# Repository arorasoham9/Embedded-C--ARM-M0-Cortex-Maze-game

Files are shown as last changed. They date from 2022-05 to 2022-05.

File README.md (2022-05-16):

# MazeGame

Links to Parts:
Adafruit LIS3DH Triple-Axis Accelerometer (+-2g/4g/8g/16g) : ID 2809 : $4.95 : Adafruit Industries, Unique & fun DIY electronics and kits
Mini Metal Speaker w/ Wires - 8 ohm 0.5W : ID 1890 : $1.95 : Adafruit Industries, Unique & fun DIY electronics and kits

What kinds of internal peripherals will you use? (at least four)
SPI (Screen), I2C (Accelerometer), Timer (Game time), DAC (Game music), GPIO (Buttons)

What kinds of external interface formats will you use? (at least two)
SPI, I2C, GPIO, Analog

Briefly, what are you making and what are you making it out of?
We are going to make a handheld maze game where you control the ball’s movement by rotating the device relative to gravity. The game will be displayed on the MSP2202 TFT LCD Display and angular position will be provided by an LIS3DH triple-axis accelerometer. Tetris music will be played with the MIDI interpreter used in lab via a M2850-8B-0L03R speaker powered by an LM386 audio amplifier. The LM386 is designed for low voltage consumer applications and is adequately powered by a 5 volt supply. The 24AA32AF EEPROM will save the high score even after the device is shut down and restarted. Five tactile push buttons (up/down/left/right/select) will allow the user to navigate any necessary prompts and menus.

Mazes will be dynamically generated. As mazes are completed, they will increase in size and number of rotations required to solve them. A reasonable minimum/maximum rotation limit will be put in place for each size of maze generated.

Briefly, how will you demonstrate it?
We will have the TA play the game. Each maze must be completed within a time limit or the speaker will buzz. The score achieved and the all-time high score will be displayed. The player will be given the choice to start a new game.

Briefly, how will we define the criteria for a successful project? (If your demonstration does not meet these criteria, your score will be negatively affected.)
The rotation based control should track the device’s position accurately and be free of noise/glitches. The game should be able to be played and completed by any adult with no instructions given (any instructions should be easily accessible within the device itself). The maze levels should gradually increase in size as each subsequent maze is completed. The maze size will level off at a point before the maze paths become hard to discern (however we expect people to lose or quit before this point is reached). The player’s score should be a summation of the time left on the countdown for each maze successfully completed. For example, if a certain level has a time limit of 45 seconds, and the player completes the maze in 30 seconds, 15 points will be added to the player’s total score. The high score should be saved and able to be recalled even after the device is shutdown and powered back on. Music should be clearly audible and free of noise.

#CONCLUSION

What did you build? 	
What components (including model numbers) did you use? 	
What challenges did you face, and how did you overcome them? 	
What do you recommend to anyone doing the same thing or using the same components in the future?

We built a maze game that was controlled by rotation of the board. The maze was dynamically generated and increased in size when each level was passed. Players had a set amount of time, which increased as the game continued, to solve each level. Time remaining and current score were displayed on the maze screen. Level score was equal to the amount of time remaining to complete the maze. Menus at start, next level, and end of game were navigated using push buttons and GPIO. After the level or game ended, score was displayed and the player could choose to continue/quit or start a new game. Navigation within the maze was controlled by an accelerometer that interfaced with I2C. EEPROM was used with I2C to save the high score when the game was reset or power was turned off and on. Tetris music played during gameplay and was set up with a MIDI interpreter and DAC output.
The game was displayed on the MSP2202 TFT LCD Display and angular position was provided by an LIS3DH triple-axis accelerometer. 24AA32AF EEPROM allowed our team to save the high score after power cycles. An LM386 amplifier drove a small 0.5 watt M2850-8B-0L03R speaker. Generic 6mm buttons provided the user-input, and LM1117 regulators allowed the team to power the components at their respective voltages.
One major issue that we encountered was related to the randomness of the maze that we were generating. When we initially wrote the maze program we used time.h to seed the random number generator. However, we learned that time.h cannot be used in our microcontroller. After this, we followed the directions on the references site about seeding random with a timer. Our first attempt at this failed and the mazes were still not random. We realized that this was due to the fact that we were calling srand(TIM2->CNT) at the same time each time the game started. In order to fix this we waited for a button to be pressed before we seeded srand, to ensure a different seed each time. 

We also struggled to correctly display colors. We used GIMP to generate the ball, and its output was not displaying colors correctly. We got around this by copying the number of the color we wanted into the array manually. However, the color was lime green against a white background, and the lack of contrast made the ball difficult to view if the player held the maze screen far away.

One final issue we encountered involved music. We used a weak 0.5 W speaker connected to a LM386 amplifier, and getting output at a reasonable volume was difficult. We needed overly complex circuitry to get volume where you didn’t need to place your ear near the speaker to hear. We also struggled with enabling and disabling the music at correct times in the code. When music was stopped and restarted, there was a remaining contribution that interfered with the sound. To fix this, we disabled the timer and set the voices array values to zero before restarting the music. We also did not correctly set the interrupt priority for the music, and the sound clicked as a result. We did not realize this because of the low output of the speaker, but it became clear during the demonstration when we hooked up the output to the lab speakers. If we had tested with the lab speaker, we would likely have been able to fix this issue.

I would recommend a similar project to teams in the future. We ran into many challenges arriving at our final design, however all problems were manageable with proper time management and teamwork. Every component worked well with the exception of the LM386 audio amplifier. We found the LM386 to be very temperamental and prone to noise on our breadboard, and the suggested schematics in the datasheet had to be modified to attain usable results in our case. A small issue we had with the LIS3DH accelerometer was that the datasheet I2C section indicated that a repeated start bit must be sent when the master is receiving data from the accelerometer. We couldn’t figure out how to do this, but after research we found that the repeated start wasn’t necessary- sending a stop bit first followed by a start bit also functioned properly. Once this was figured out the accelerometer worked flawlessly.

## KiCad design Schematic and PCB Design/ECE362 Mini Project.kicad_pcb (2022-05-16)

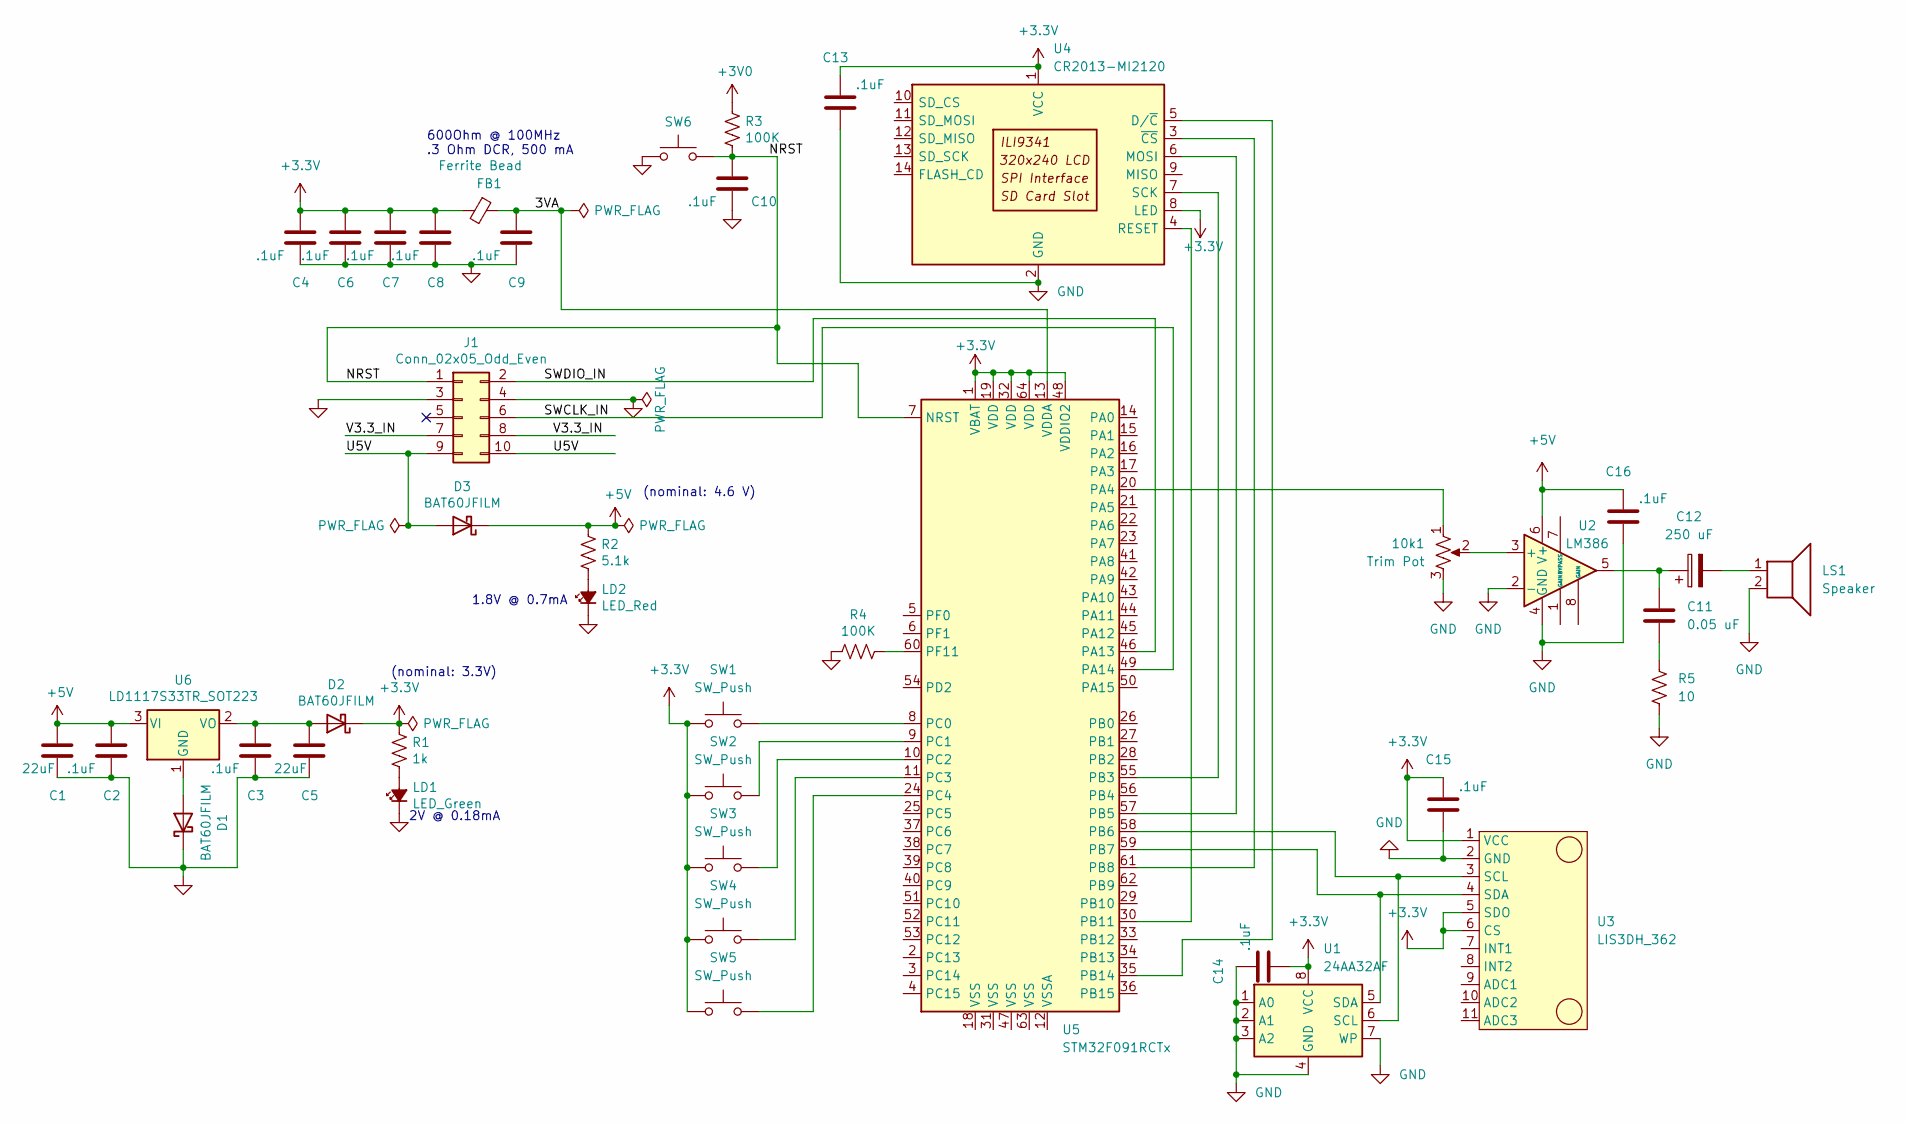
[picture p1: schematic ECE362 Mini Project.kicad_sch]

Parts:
10k1: Trim Pot; Potentiometer_Vishay_148-149_Single_Vertical
C1, C5: 22uF; C_0805_2012Metric_Pad1.18x1.45mm_HandSolder
C2, C3, C4, C6, C7, C8, C9, C10, C13, C14, C15, C16: .1uF; C_0805_2012Metric_Pad1.18x1.45mm_HandSolder
C11: 0.05 uF; C_0805_2012Metric_Pad1.18x1.45mm_HandSolder
C12: 250 uF; CP_Radial_D8.0mm_P3.50mm
D1, D2, D3: BAT60JFILM; D_SOD-323
FB1: Ferrite Bead; L_0805_2012Metric_Pad1.15x1.40mm_HandSolder
J1: Conn_02x05_Odd_Even; IDC-Header_2x05_P2.54mm_Vertical
LD1: LED_Green; LED_0805_2012Metric
LD2: LED_Red; LED_0805_2012Metric
LS1: Speaker; SolderWire-0.5sqmm_1x02_P4.6mm_D0.9mm_OD2.1mm
R1: 1k; R_0805_2012Metric_Pad1.20x1.40mm_HandSolder
R2: 5.1k; R_0805_2012Metric_Pad1.20x1.40mm_HandSolder
R3, R4: 100K; R_0805_2012Metric_Pad1.20x1.40mm_HandSolder
R5: 10; R_0805_2012Metric_Pad1.20x1.40mm_HandSolder
SW1, SW2, SW3, SW4, SW5, SW6: SW_Push; SW_PUSH_6mm
U1: 24AA32AF; DIP-8_W7.62mm
U2: LM386; DIP-8_W7.62mm
U3: LIS3DH_362
U4: CR2013-MI2120
U5: STM32F091RCTx; LQFP-64_10x10mm_P0.5mm
U6: LD1117S33TR_SOT223; SOT-223-3_TabPin2

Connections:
+3V0: R3.1
+3V3: C4.1, C6.1, C7.1, C8.1, C13.2, C14.1, C15.2, D2.1 (K), FB1.2, R1.1, SW1.1, SW2.1, SW3.1, SW4.1, SW5.1, U1.8 (VCC), U3.1 (VCC), U3.5 (SDO), U3.6 (CS), U4.1 (VCC), U4.8 (LED), U5.1 (VBAT), U5.19 (VDD), U5.32 (VDD), U5.48 (VDDIO2), U5.64 (VDD)
+5V: C1.1, C2.1, C16.2, D3.1 (K), R2.1, U2.6 (V+), U6.3 (VI)
/3VA: C9.1, FB1.1, U5.13 (VDDA)
/NRST: C10.1, J1.1, R3.2, SW6.2, U5.7 (NRST)
/SWCLK_IN: J1.6, U5.49 (PA14)
/SWDIO_IN: J1.2, U5.46 (PA13)
/U5V: D3.2 (A), J1.9, J1.10
/V3.3_IN: J1.7, J1.8
GND: 10k1.3, C1.2, C2.2, C3.2, C4.2, C5.2, C6.2, C7.2, C8.2, C9.2, C10.2, C13.1, C14.2, C15.1, C16.1, D1.1 (K), J1.3, J1.4, LD1.1 (K), LD2.1 (K), LS1.2, R4.2, R5.2, SW6.1, U1.1 (A0), U1.2 (A1), U1.3 (A2), U1.4 (GND), U1.7 (WP), U2.2 (-), U2.4 (GND), U3.2 (GND), U4.2 (GND)
unnamed: 10k1.2, U2.3 (+)
unnamed: C3.1, C5.1, D2.2 (A), U6.2 (VO)
unnamed: C11.1, C12.1, U2.5
unnamed: C11.2, R5.1
unnamed: D1.2 (A), U6.1 (GND)
unnamed: LD1.2 (A), R1.2
unnamed: LD2.2 (A), R2.2
unnamed: C12.2, LS1.1
unnamed: U1.5 (SDA), U3.4 (SDA), U5.59 (PB7)
unnamed: U4.6 (MOSI), U5.57 (PB5)
unnamed: SW1.2, U5.8 (PC0)
unnamed: SW2.2, U5.9 (PC1)
unnamed: SW3.2, U5.10 (PC2)
unnamed: SW4.2, U5.11 (PC3)
unnamed: 10k1.1, U5.20 (PA4)
unnamed: SW5.2, U5.24 (PC4)
unnamed: U4.4 (RESET), U5.30 (PB11)
unnamed: U4.5 (D/~C), U5.35 (PB14)
unnamed: U4.7 (SCK), U5.55 (PB3)
unnamed: U1.6 (SCL), U3.3 (SCL), U5.58 (PB6)
unnamed: R4.1, U5.60 (PF11)
unnamed: U4.3 (~CS), U5.61 (PB8)

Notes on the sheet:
(nominal: 3.3V)
2V @ 0.18mA
600Ohm @ 100MHz .3 Ohm DCR, 500 mA
1.8V @ 0.7mA
(nominal: 4.6 V)

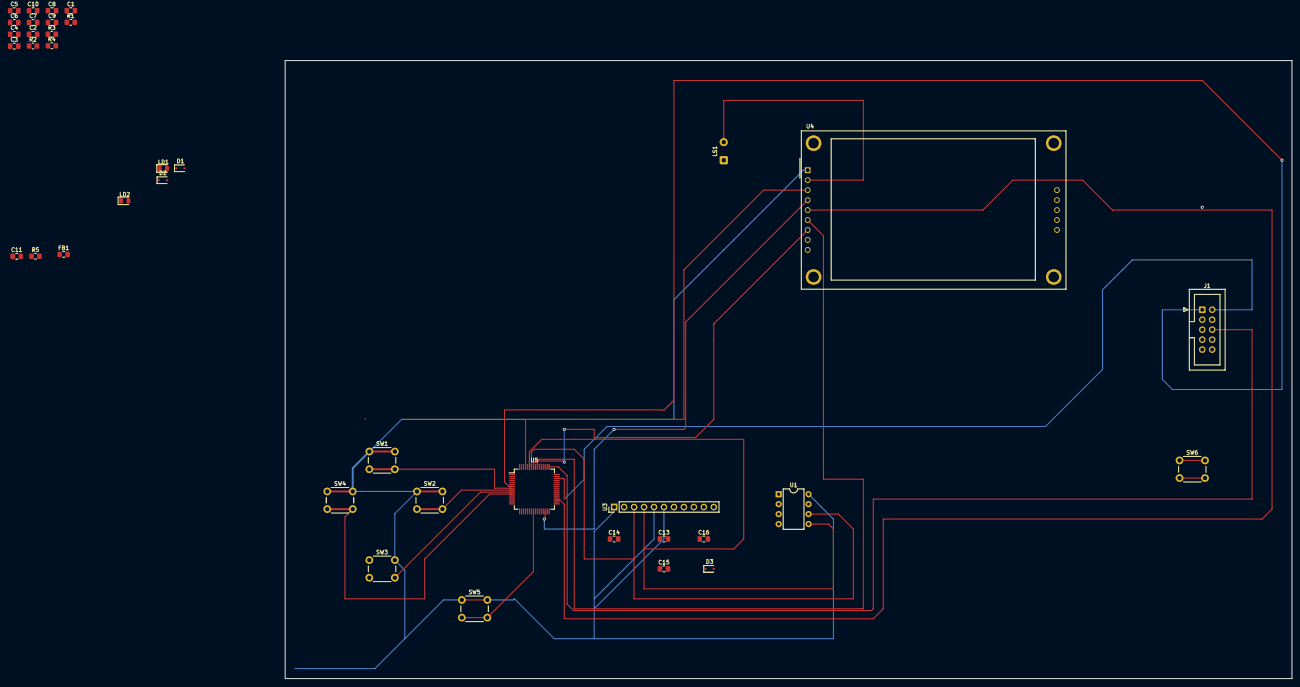
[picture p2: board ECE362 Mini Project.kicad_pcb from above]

Board: 2 copper layers, 256.5 x 157.5 mm, 39 parts (1 on the bottom side), 27 nets.

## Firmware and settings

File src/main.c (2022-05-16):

#include "stm32f0xx.h"
#include <string.h>
#include "lcd.h"
#include "speaker.h"
#include "midi.h"
char** generate_maze(int, int);
void destroyArray(char** arr);
//extern const Picture background; // A 240x320 background image
MIDI_Player * music;
int time_remaining;
int current_score = 0;
int high_score = 0;
int num_rows = 13;
int num_cols = 13;
int game_number = 0;
int level_score = 60;

int up = 0;
int down = 0;
int left = 0;
int right = 0;
int ball_row = 1;
int ball_col = 1;

char ** global_maze;

//===========================================================================
// GIMP images
//===========================================================================
/* GIMP RGB C-Source image dump (line.c) */
static const struct {
  unsigned int      width;
  unsigned int      height;
  unsigned int      bytes_per_pixel; /* 2:RGB16, 3:RGB, 4:RGBA */
  unsigned char     pixel_data[8 * 8 * 3 + 1];
} line = {
  8, 8, 3,
  "\000\000\000\000\000\000\000\000\000\000\000\000\000\000\000\000\000\000\000\000\000\000\000\000\000\000\000\000\000\000\000\000\000\000\000\000"
  "\000\000\000\000\000\000\000\000\000\000\000\000\000\000\000\000\000\000\000\000\000\000\000\000\000\000\000\000\000\000\000\000\000\000\000\000"
  "\000\000\000\000\000\000\000\000\000\000\000\000\000\000\000\000\000\000\000\000\000\000\000\000\000\000\000\000\000\000\000\000\000\000\000\000"
  "\000\000\000\000\000\000\000\000\000\000\000\000\000\000\000\000\000\000\000\000\000\000\000\000\000\000\000\000\000\000\000\000\000\000\000\000"
  "\000\000\000\000\000\000\000\000\000\000\000\000\000\000\000\000\000\000\000\000\000\000\000\000\000\000\000\000\000\000\000\000\000\000\000\000"
  "\000\000\000\000\000\000\000\000\000\000\000\000",
};
/* GIMP RGB C-Source image dump (green_square.c) */

static const struct {
  unsigned int   width;
  unsigned int   height;
  unsigned int   bytes_per_pixel; // 2:RGB16, 3:RGB, 4:RGBA
  unsigned char  pixel_data[8 * 8 * 2 + 1];
} ball = {
  8, 8, 2,
  "\262_\262_\262_\262_\262_\262_\262_\262_\262_\262_\262_\262_\262_\262_\262_\262_\262_\262_\262_\262_\262_\262_\262_\262_\262_\262_\262_"
  "\262_\262_\262_\262_\262_\262_\262_\262_\262_\262_\262_\262_\262_\262_\262_\262_\262_\262_\262_\262_\262_\262_\262_\262_\262_\262_\262_"
  "\262_\262_\262_\262_\262_\262_\262_\262_\262_\262_\262_\262_\262_\262_\262_\262_\262_\262_\262_\262_\262_\262_\262_\262_\262_\262_\262_"
  "\262_\262_\262_\262_\262_\262_\262_\262_\262_\262_\262_\262_\262_\262_\262_\262_\262_\262_\262_\262_\262_\262_\262_\262_\262_\262_\262_"
  "\262_\262_\262_\262_\262_\262_\262_\262_\262_\262_\262_\262_\262_\262_\262_\262_\262_\262_\262_\262_\262_\262_\262_\262_\262_\262_\262_"
  "\262_\262_\262_\262_\262_\262_\262_\262_\262_\262_\262_\262_\262_\262_\262_\262_\262_\262_\262_\262_\262_\262_\262_\262_\262_\262_\262_"
  "\262_\262_\262_\262_\262_\262_\262_\262_\262_\262_\262_\262_\262_\262_\262_\262_\262_\262_\262_\262_\262_\262_\262_\262_\262_\262_\262_"
  "\262_\262_\262_",
};
/* GIMP RGB C-Source image dump (white_square.c) */
static const struct {
  unsigned int   width;
  unsigned int   height;
  unsigned int   bytes_per_pixel; /* 2:RGB16, 3:RGB, 4:RGBA */
  unsigned char  pixel_data[8 * 8 * 3 + 1];
} white_square = {
  8, 8, 3,
  "\377\377\377\377\377\377\377\377\377\377\377\377\377\377\377\377\377\377"
  "\377\377\377\377\377\377\377\377\377\377\377\377\377\377\377\377\377\377"
  "\377\377\377\377\377\377\377\377\377\377\377\377\377\377\377\377\377\377"
  "\377\377\377\377\377\377\377\377\377\377\377\377\377\377\377\377\377\377"
  "\377\377\377\377\377\377\377\377\377\377\377\377\377\377\377\377\377\377"
  "\377\377\377\377\377\377\377\377\377\377\377\377\377\377\377\377\377\377"
  "\377\377\377\377\377\377\377\377\377\377\377\377\377\377\377\377\377\377"
  "\377\377\377\377\377\377\377\377\377\377\377\377\377\377\377\377\377\377"
  "\377\377\377\377\377\377\377\377\377\377\377\377\377\377\377\377\377\377"
  "\377\377\377\377\377\377\377\377\377\377\377\377\377\377\377\377\377\377"
  "\377\377\377\377\377\377\377\377\377\377\377\377",
};

//===========================================================================
// I2C Functions
//===========================================================================
#define LIS3DH_ADDR 0x19  // LIS3DH ACCELEROMETER I2C ADDRESS
#define LIS3DH_CTRL_REG1 0x20
#define LIS3DH_OUT_X_L 0xA8 // MSB bit set to enable multiple register reading
#define LIS3DH_OUT_Y_L 0xAA // MSB bit set to enable multiple register reading
#define LIS3DH_OUT_Z_L 0xAC // MSB bit set to enable multiple register reading

void init_i2c(void) {
    RCC->AHBENR |= RCC_AHBENR_GPIOBEN;
    RCC->APB1ENR |= RCC_APB1ENR_I2C1EN;

    GPIOB->MODER |= 2<<(2*6) | 2<<(2*7);
    GPIOB->AFR[0] |= 1<<(4*6) | 1<<(4*7);

    I2C1->CR1 &= ~I2C_CR1_PE; // Disable channel
    I2C1->CR1 &= ~I2C_CR1_ANFOFF; // Turn on analog noise filter
    I2C1->CR1 &= ~I2C_CR1_ERRIE; // Disable error interrupt
    I2C1->CR1 &= ~I2C_CR1_NOSTRETCH; // Enable clock stretching

    I2C1->TIMINGR = 0;
    I2C1->TIMINGR &= ~I2C_TIMINGR_PRESC;// Clear prescaler
    I2C1->TIMINGR |= 0 << 28;           // Set prescaler to 0
    I2C1->TIMINGR |= 3 << 20;           // SCLDEL
    I2C1->TIMINGR |= 1 << 16;           // SDADEL
    I2C1->TIMINGR |= 3 << 8;            // SCLH
    I2C1->TIMINGR |= 9 << 0;            // SCLL

    // Disable both "own addresses"
    I2C1->OAR1 &= ~I2C_OAR1_OA1EN;
    I2C1->OAR1 = I2C_OAR1_OA1EN | 0x2;
    I2C1->OAR2 &= ~I2C_OAR2_OA2EN;

    I2C1->CR2 &= ~I2C_CR2_ADD10; // Configure for 7-bit mode
    I2C1->CR2 |= I2C_CR2_AUTOEND; // Enable auto end
    //I2C1->CR2 |= I2C_CR2_NACK; // Should I have this?

    I2C1->CR1 |= I2C_CR1_PE; // Enable channel
}

void i2c_waitidle(void) {
    while ( (I2C1->ISR & I2C_ISR_BUSY) == I2C_ISR_BUSY); // while busy, wait
}

void i2c_start(uint32_t devaddr, uint8_t size, uint8_t dir) {
    // dir: 0 = master requests a write transfer
    // dir: 1 = master requests a read transfer
    uint32_t tmpreg = I2C1->CR2;
    tmpreg &= ~(I2C_CR2_SADD | I2C_CR2_NBYTES |
                I2C_CR2_RELOAD | I2C_CR2_AUTOEND |
                I2C_CR2_RD_WRN | I2C_CR2_START | I2C_CR2_STOP);
    if (dir == 1)
        tmpreg |= I2C_CR2_RD_WRN; // Read from slave
    else
        tmpreg &= ~I2C_CR2_RD_WRN; // Write to slave
    tmpreg |= ((devaddr<<1) & I2C_CR2_SADD) | ((size << 16) & I2C_CR2_NBYTES);
    tmpreg |= I2C_CR2_START;
    I2C1->CR2 = tmpreg;
}

void i2c_stop(void) {
    if (I2C1->ISR & I2C_ISR_STOPF)
        return;
    // Master: Generate STOP bit after current byte has been transferred
    I2C1->CR2 |= I2C_CR2_STOP;
    // Wait until STOPF flag is reset
    while ( (I2C1->ISR & I2C_ISR_STOPF) == 0);
    I2C1->ICR |= I2C_ICR_STOPCF; // Write to clear STOPF flag
}

int i2c_checknack(void) {
    if ((I2C1->ISR & I2C_ISR_NACKF) == 1)
            return 1;
    else
        return 0;
}

void i2c_clearnack(void) {
    I2C1->ICR |= I2C_ICR_NACKCF;
}

int i2c_senddata(uint8_t devaddr, const void *data, uint8_t size) {
    int i;
    if (size <= 0 || data == 0) return -1;
    uint8_t *udata = (uint8_t*)data;
    i2c_waitidle();
    // Last argument is dir: 0 = sending data to the slave device
    i2c_start(devaddr, size, 0);

    for(i=0; i<size; i++){
        // TXIS bit is set by hardware when the TXDR register is empty and the
        // data to be transmitted must be written in the TXDR register. It is
        // cleared when the next data to be sent is written in the TXDR register.
        // The TXIS flag is not set when a NACK is recieved.
        int count = 0;
        while( (I2C1->ISR & I2C_ISR_TXIS) == 0){
            count +=  1;
            if (count > 1000000) return -1;
            if (i2c_checknack()) { i2c_clearnack(); i2c_stop(); return -1;}
        }
        // TXIS is cleared by writing to the TXDR register.
        I2C1->TXDR = udata[i] & I2C_TXDR_TXDATA;
    }
    // Wait until TC flag is set or the NACK flag is set
    while((I2C1->ISR & I2C_ISR_TC) == 0 && (I2C1->ISR & I2C_ISR_NACKF) == 0);
    if ((I2C1->ISR & I2C_ISR_NACKF) != 0)
        return -1;
    i2c_stop();
    return 0;
}

int i2c_recvdata(uint8_t devaddr, void *data, uint8_t size) {
    int i;
    if (size <= 0 || data == 0) return -1;
    uint8_t *udata = (uint8_t*)data;
    i2c_waitidle();
    // Last argument is dir: 1 = receiving data from the slave device.
    i2c_start(devaddr, size, 1);
    for(i=0; i<size; i++){
        int count = 0;
        while ((I2C1->ISR & I2C_ISR_RXNE) == 0){
            count += 1;
            if (count > 1000000) return -1;
            if (i2c_checknack()) { i2c_clearnack(); i2c_stop(); return -1;}
        }
        udata[i] = I2C1->RXDR;
    }
    // Wait until TX flag is set or the NACK flag is set;
    while((I2C1->ISR & I2C_ISR_TC) == 0 && (I2C1->ISR & I2C_ISR_NACKF) == 0);
    if ((I2C1->ISR & I2C_ISR_NACKF) != 0)
        return -1;
    i2c_stop();
    return 0;
}


//===========================================================================
// Accelerometer (lis3dh)
//===========================================================================
void lis3dh_setup(void){
    uint8_t ctrl_reg1_config = 0x57; // 100hz mode, enable x/y/z
    uint8_t data[2] = {LIS3DH_CTRL_REG1, ctrl_reg1_config};
    i2c_senddata(LIS3DH_ADDR, data, 2);
}

void lis3dh_get_x(int16_t* x){
    uint8_t reg[1] = {LIS3DH_OUT_X_L};
    uint8_t data[2] = {0, 0};

    i2c_senddata(LIS3DH_ADDR, reg, 1);
    i2c_recvdata(LIS3DH_ADDR, data, 2);

    *x = *((int16_t*)data);
}

void lis3dh_get_y(int16_t* y){
    uint8_t reg[1] = {LIS3DH_OUT_Y_L};
    uint8_t data[2] = {0, 0};

    i2c_senddata(LIS3DH_ADDR, reg, 1);
    i2c_recvdata(LIS3DH_ADDR, data, 2);

    *y = *((int16_t*)data);
}

void lis3dh_get_z(int16_t* z){
    uint8_t reg[1] = {LIS3DH_OUT_Z_L};
    uint8_t data[2] = {0, 0};

    i2c_senddata(LIS3DH_ADDR, reg, 1);
    i2c_recvdata(LIS3DH_ADDR, data, 2);

    *z = *((int16_t*)data);
}

//===========================================================================
// EEPROM
//===========================================================================
void eeprom_write(uint16_t loc, const char* data, uint8_t len) {
    TIM6->CR1 &= ~TIM_CR1_CEN;
    TIM2->CR1 &= ~TIM_CR1_CEN;
    TIM7->CR1 &= ~TIM_CR1_CEN;
    uint8_t new_data[34];
    new_data[0] = loc >> 8;
    new_data[1] = loc & 0xff;
    for (int i = 2; i < 34; i++) {
        new_data[i] = data[i-2];
    }
    i2c_senddata(0x50, new_data, 34);
    TIM6->CR1 |= TIM_CR1_CEN;
    TIM2->CR1 |= TIM_CR1_CEN;
    TIM7->CR1 |= TIM_CR1_CEN;
}

int eeprom_write_complete(void) {
    i2c_waitidle();
    i2c_start(0x50, 0, 0);
    // Wait until TC flag is set or the NACK flag is set
    while((I2C1->ISR & I2C_ISR_TC) == 0 && (I2C1->ISR & I2C_ISR_NACKF) == 0);
    int nack = i2c_checknack();
    if (nack) {
        i2c_clearnack();
        i2c_stop();
        return 0;
    }
    else {
        i2c_stop();
        return 1;
    }
}

void eeprom_read(uint16_t loc, char data[], uint8_t len) {
    //TIM7->CR1 &= ~TIM_CR1_CEN; // Pause keypad scanning.
    TIM6->CR1 &= ~TIM_CR1_CEN;
    TIM2->CR1 &= ~TIM_CR1_CEN;
    TIM7->CR1 &= ~TIM_CR1_CEN;

    uint8_t locat[2] = {loc >> 8, loc & 0xff};
    i2c_senddata(0x50, locat, 2);
    i2c_recvdata(0x50, data, len);

    //TIM7->CR1 |= TIM_CR1_CEN; // Resume keypad scanning.
    TIM6->CR1 |= TIM_CR1_CEN;
    TIM2->CR1 |= TIM_CR1_CEN;
    TIM7->CR1 |= TIM_CR1_CEN;
}


void eeprom_blocking_write(uint16_t loc, const char* data, uint8_t len) {
    TIM6->CR1 &= ~TIM_CR1_CEN;
    TIM2->CR1 &= ~TIM_CR1_CEN;
    TIM7->CR1 &= ~TIM_CR1_CEN;
    //TIM7->CR1 &= ~TIM_CR1_CEN; // Pause keypad scanning.
    eeprom_write(loc, data, len);
    while (!eeprom_write_complete());
    //TIM7->CR1 |= TIM_CR1_CEN; // Resume keypad scanning.
    TIM6->CR1 |= TIM_CR1_CEN;
    TIM2->CR1 |= TIM_CR1_CEN;
    TIM7->CR1 |= TIM_CR1_CEN;
}

//===========================================================================
// SPI
//===========================================================================
void init_lcd_spi(void)
{
    RCC->AHBENR |= RCC_AHBENR_GPIOBEN;
    GPIOB->MODER &= ~(GPIO_MODER_MODER8 | GPIO_MODER_MODER11 | GPIO_MODER_MODER14);
    GPIOB->MODER |= GPIO_MODER_MODER8_0 | GPIO_MODER_MODER11_0 | GPIO_MODER_MODER14_0;
    GPIOB->ODR |= GPIO_ODR_8 | GPIO_ODR_11 | GPIO_ODR_14;
    GPIOB->MODER |= GPIO_MODER_MODER3 | GPIO_MODER_MODER5;
    GPIOB->MODER &= ~(GPIO_MODER_MODER3_0 | GPIO_MODER_MODER5_0);

    RCC->APB2ENR |= RCC_APB2ENR_SPI1EN;
    SPI1->CR1 &= ~SPI_CR1_SPE;
    SPI1->CR1 &= ~SPI_CR1_BR;
    SPI1->CR1 |= SPI_CR1_MSTR;
    SPI1->CR2 = SPI_CR2_DS_0 | SPI_CR2_DS_1 | SPI_CR2_DS_2;
    SPI1->CR1 |= SPI_CR1_SSM | SPI_CR1_SSI;
    SPI1->CR1 |= SPI_CR1_SPE;
}

//===========================================================================
// Push buttons
//===========================================================================
void setup_buttons(void)
{
    RCC->AHBENR |= RCC_AHBENR_GPIOCEN;
    GPIOC->MODER &= ~0x3ff;
    GPIOC->PUPDR &= ~0x3ff;
    GPIOC->PUPDR |= 0x2aa;
}

//===========================================================================
// Maze generation
//===========================================================================
void draw_maze(char** arr)
{
    //LCD_DrawPicture(0,0,&background); // if we want a non-plain background
    LCD_Clear(0xffffff);
    int x_inc = 8;
    int y_inc = 8;
    int x_pos = 0;
    int y_pos = 0;
    arr[num_rows-2][num_cols-1] = ' ';
    //arr[0][1] = ' ';
    for (int x = 0; x < num_rows; x++) {
        for (int y = 0; y < num_cols; y++) {
            /*
            if (x == (num_rows - 2) && (y == (num_cols -  1))) {
                LCD_DrawPicture(x_pos, y_pos, &line_green);
            }
            */
            if (arr[x][y] == '|') {
                LCD_DrawPicture(x_pos, y_pos, &line);

            }
            x_pos += x_inc;
        }
        y_pos += y_inc;
        x_pos = 0;
    }
}

//===========================================================================
// Game logic
//===========================================================================
void init_tim6(void) {
    TIM6->CR1 &= ~TIM_CR1_CEN;

    time_remaining = 45+game_number;
    level_score = time_remaining;
    RCC->APB1ENR |= RCC_APB1ENR_TIM6EN;
    TIM6->PSC = 48000-1;
    TIM6->ARR = 1000-1;
    TIM6->DIER |= TIM_DIER_UIE;
    NVIC->ISER[0] = 1<<TIM6_DAC_IRQn;
    TIM6->CR1 |= TIM_CR1_CEN;
}

void TIM6_DAC_IRQHandler(void) {
    char string[20];
    char score_string[20];
    TIM6->SR &= ~TIM_SR_UIF;
    time_remaining--;
    level_score -= 1;

    //sprintf(score_string, "Level: %d", level_score);
    //LCD_DrawString(140, 275, BLACK, WHITE,  (score_string), 16, 0);
    sprintf(score_string, "Score: %d", current_score);
    LCD_DrawString(140, 300, BLACK, WHITE,  (score_string), 16, 0);

    if (time_remaining == 9) {
        LCD_DrawString(5, 300, BLACK, WHITE, "Time: 9 ", 16, 0);
    }
    else if (time_remaining <= 5) {
        sprintf(string, "Time: %d", time_remaining);
        LCD_DrawString(5, 300, RED, WHITE,  (string), 16, 0);
    }
    else {
        sprintf(string, "Time: %d", time_remaining);
        LCD_DrawString(5, 300, BLACK, WHITE,  (string), 16, 0);
    }

    if (time_remaining == 0) {
        stopMusic();
        end_game();
    }
}

void next_level() {
    LCD_Clear(0xffffff);
    destroyArray(global_maze);
    TIM6->CR1 &= ~TIM_CR1_CEN;
    TIM7->CR1 &= ~TIM_CR1_CEN;
    TIM2->CR1 &= ~TIM_CR1_CEN;

    ball_row = 1;
    ball_col = 1;
    game_number += 1;

    if (num_cols < 29) {
        num_cols += 2;
    }
    else if (num_rows < 33) {
        num_rows += 2;
    }

    TIM2->CR1 |= TIM_CR1_CEN;

    start_game();
}

static void nano_wait(unsigned int n) {
    asm(    "        mov r0,%0\n"
            "repeat: sub r0,#83\n"
            "        bgt repeat\n" : : "r"(n) : "r0", "cc");
}

void end_game(void) {
    stopMusic();
    free(music);
    LCD_Clear(0xffffff);

    LCD_DrawString(80, 50, RED, WHITE,  "GAME OVER", 16, 0);
    char score_string[20];
    //current_score += level_score;
    if (current_score > high_score) {
        high_score = current_score;
        char score[5];
        sprintf(score, "%d", high_score);
        eeprom_write(0, score, 4);

        sprintf(score_string, "New high score: %d", high_score);
        LCD_DrawString(45, 150, GREEN, WHITE,  score_string, 16, 0);
    }
    else {
        sprintf(score_string, "High score: %d", high_score);
        LCD_DrawString(50, 150, BLACK, WHITE,  (score_string), 16, 0);
    }
    sprintf(score_string, "Level score: %d", level_score);
    LCD_DrawString(50, 100, BLACK, WHITE,  (score_string), 16, 0);
    sprintf(score_string, "Total score: %d", current_score);
    LCD_DrawString(50, 125, BLACK, WHITE,  (score_string), 16, 0);
    LCD_DrawString(75, 225, BLACK, WHITE,  "Play again?", 16, 0);
    LCD_DrawString(60, 250, BLACK, WHITE,  "(Press Select)", 16, 0);

    int select = GPIOC->IDR >> 4 & 1;
    while(select == 0) {
        nano_wait(1000000);
        select = GPIOC->IDR >> 4 & 1;
    }
    game_number = 0;
    ball_row = 1;
    ball_col = 1;
    num_rows = 13;
    num_cols = 13;
    current_score = 0;
    srandom(TIM2->CNT);

    game_logic();
}

void game_logic(void) {
//    startMusic(music);
    unmuteMusic(music);
    char** arr = generate_maze(num_rows, num_cols);
    draw_maze(arr);
    LCD_DrawPicture(8, 8, &ball);
    init_tim6();
    init_tim7();
    global_maze = arr;
    game_number += 1;
}

init_tim7(void) {
    RCC->APB1ENR |= RCC_APB1ENR_TIM7EN;
    TIM7->CR1 &= ~TIM_CR1_CEN;
    TIM7->PSC = 48000-1;
    TIM7->ARR = 175-1;
    TIM7->DIER |= TIM_DIER_UIE;
    NVIC->ISER[0] = 1<<TIM7_IRQn;
    TIM7->CR1 |= TIM_CR1_CEN;
}

void TIM7_IRQHandler(void) {
    if(checkMusicStatus(music)){
//       startMusic(music);
        unmuteMusic(music);
}
    TIM7->SR &= ~TIM_SR_UIF;
    update_orientation();
    navigate_maze();
}

void update_orientation(){
    int16_t x = 0;
    int16_t y = 0;
    int16_t z = 0;

    lis3dh_get_x(&x);
    lis3dh_get_y(&y);
    lis3dh_get_z(&z);

    if (y < -15000){
        up = 1;
        down = 0;
        left = 0;
        right = 0;
    }
    else if (y > 15000){
        up = 0;
        down = 1;
        left = 0;
        right = 0;
    }
    else if (x < -15000){
        up = 0;
        down = 0;
        left = 1;
        right = 0;
    }
    else if (x > 15000){
        up = 0;
        down = 0;
        left = 0;
        right = 1;
    }
    else{
        up = 0;
        down = 0;
        left = 0;
        right = 0;
    }
    // Debug DrawString statements
    /*
    char x_string[20];
    char y_string[20];
    char z_string[20];
    sprintf(x_string, "X Accel: %d", x);
    sprintf(y_string, "Y Accel: %d", y);
    sprintf(z_string, "Z Accel: %d", z);
    LCD_DrawString(50, 150, BLACK, WHITE,  (x_string), 16, 0);
    LCD_DrawString(50, 170, BLACK, WHITE,  (y_string), 16, 0);
    LCD_DrawString(50, 190, BLACK, WHITE,  (z_string), 16, 0);
    */
}

void navigate_maze() {
    if ((ball_row == num_rows-2) && (ball_col == num_cols-1)) {
    //if ((ball_row == 1) && (ball_col == 1)) {
        //stopping music here to begin again later
        stopMusic();
        next_level();
    }
    else if (up && global_maze[ball_row-1][ball_col] == ' ') {
        LCD_DrawPicture(ball_col*8, ball_row*8, &white_square);
        ball_row -= 1;
        LCD_DrawPicture(ball_col*8, ball_row*8, &ball);
    }
    else if (down && global_maze[ball_row + 1][ball_col] == ' ') {
        LCD_DrawPicture(ball_col*8, ball_row*8, &white_square);
        ball_row += 1;
        LCD_DrawPicture(ball_col*8, ball_row*8, &ball);
    }
    else if (left && global_maze[ball_row][ball_col-1] == ' ') {
        LCD_DrawPicture(ball_col*8, ball_row*8, &white_square);
        ball_col -= 1;
        LCD_DrawPicture(ball_col*8, ball_row*8, &ball);
    }
    else if (right && global_maze[ball_row][ball_col+1] == ' ') {
        LCD_DrawPicture(ball_col*8, ball_row*8, &white_square);
        ball_col += 1;
        LCD_DrawPicture(ball_col*8, ball_row*8, &ball);
    }
}
void clear_high_score(void){
    eeprom_write(0,0,4);
}
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
int main(void) {
    setup_buttons();
    LCD_Setup();
    init_i2c();
//    clear_high_score();

    lis3dh_setup();
    startMusic(music);
    stopMusic();
    start_game();

}

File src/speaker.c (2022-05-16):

#include "stm32f0xx.h"
#include <stdint.h>

#include "midi.h"
#include "midiplay.h"

// The number of simultaneous voices to support.
#define VOICES 15

// An array of "voices".  Each voice can be used to play a different note.
// Each voice can be associated with a channel (explained later).
// Each voice has a step size and an offset into the wave table.
struct {
    uint8_t in_use;
    uint8_t note;
    uint8_t chan;
    uint8_t volume;
    int     step;
    int     offset;
} voice[VOICES];

// We'll use the Timer 6 IRQ to recompute samples and feed those
// samples into the DAC.

void makeVoiceZero(){
    for(int i =0; i<VOICES;i++){
        voice[i].in_use =  0;
        voice[i].note =  0;
        voice[i].chan =  0;
        voice[i].volume=  0;
        voice[i].step  =  0;
        voice[i].offset =  0;
    }
}
void TIM15_IRQHandler(void)
{
    // TODO: Remember to acknowledge the interrupt right here.
    TIM15->SR &= ~1; //interrupt acknowledged.


    int sample = 0;
    for(int x=0; x < sizeof voice / sizeof voice[0]; x++) {
        if (voice[x].in_use) {
            voice[x].offset += voice[x].step;
            if (voice[x].offset >= N<<16)
                voice[x].offset -= N<<16;
            sample += (wavetable[voice[x].offset>>16] * voice[x].volume) >> 4;
        }
    }
    sample = (sample >> 10) + 2048;
    if (sample > 4095)
        sample = 4095;
    else if (sample < 0)
        sample = 0;
    DAC->DHR12R1 = sample;
}

// Initialize the DAC so that it can output analog samples
// on PA4.  Configure i==========
void init_dac(void)
{
    // TODO: you fill this in.

    RCC->APB1ENR |= RCC_APB1ENR_DACEN;
    DAC->CR |= 3<<3;
    DAC->CR |= DAC_CR_TEN1;
    DAC->CR |= DAC_CR_EN1;
}

// Initialize Timer 6 so that it calls TIM6_DAC_IRQHandler
// at exactly RATE times per second.  You'll need to select
// a PSC value and then do some math on the system clock rate
// to determine the value to set for ARR.  Set it to trigger
// the DAC by enabling the Update Tigger in the CR2 MMS field.
void init_tim15(void)
{
    // TODO: you fill this in.
      RCC->APB2ENR |= (1<<16);//clock
      TIM15->PSC = 0;
      TIM15->ARR = 48000000/RATE -1;
      TIM15->CR2 &= ~(7<<4);
      TIM15->CR2 |= (2<<4);
      TIM15->DIER |= 1;
      TIM15->CR1 |= 1;
      NVIC->ISER[0] = 1<<20;

}

// Find the voice current playing a note, and turn it off.
void note_off(int time, int chan, int key, int velo)
{
    int n;
    for(n=0; n<sizeof voice / sizeof voice[0]; n++) {
        if (voice[n].in_use && voice[n].note == key) {
            voice[n].in_use = 0; // disable it first...
            voice[n].chan = 0;   // ...then clear its values
            voice[n].note = key;
            voice[n].step = step[key];
            return;
        }
    }
}

// Find an unused voice, and use it to play a note.
void note_on(int time, int chan, int key, int velo)
{
    if (velo == 0) {
        note_off(time, chan, key, velo);
        return;
    }
    int n;
    for(n=0; n<sizeof voice / sizeof voice[0]; n++) {
        if (voice[n].in_use == 0) {
            voice[n].note = key;
            voice[n].step = step[key];
            voice[n].offset = 0;
            voice[n].volume = velo;
            voice[n].chan = chan;
            voice[n].in_use = 1;
            return;
        }
    }
}

void set_tempo(int time, int value, const MIDI_Header *hdr)
{
    // This assumes that the TIM2 prescaler divides by 48.
    // It sets the timer to produce an interrupt every N
    // microseconds, where N is the new tempo (value) divided by
    // the number of divisions per beat specified in the MIDI file header.
    TIM3->ARR = value/hdr->divisions - 1;
}

const float pitch_array[] = {
0.943874, 0.945580, 0.947288, 0.948999, 0.950714, 0.952432, 0.954152, 0.955876,
0.957603, 0.959333, 0.961067, 0.962803, 0.964542, 0.966285, 0.968031, 0.969780,
0.971532, 0.973287, 0.975046, 0.976807, 0.978572, 0.980340, 0.982111, 0.983886,
0.985663, 0.987444, 0.989228, 0.991015, 0.992806, 0.994599, 0.996396, 0.998197,
1.000000, 1.001807, 1.003617, 1.005430, 1.007246, 1.009066, 1.010889, 1.012716,
1.014545, 1.016378, 1.018215, 1.020054, 1.021897, 1.023743, 1.025593, 1.027446,
1.029302, 1.031162, 1.033025, 1.034891, 1.036761, 1.038634, 1.040511, 1.042390,
1.044274, 1.046160, 1.048051, 1.049944, 1.051841, 1.053741, 1.055645, 1.057552,
};

void pitch_wheel_change(int time, int chan, int value)
{
    //float multiplier = pow(STEP1, (value - 8192.0) / 8192.0);
    float multiplier = pitch_array[value >> 8];
    for(int n=0; n<sizeof voice / sizeof voice[0]; n++) {
        if (voice[n].in_use && voice[n].chan == chan) {
            voice[n].step = step[voice[n].note] * multiplier;
        }
    }
}



// Configure timer 2 so that it invokes the Update interrupt
// every n microseconds.  To do so, set the prescaler to divide
// by 48.  Then the CNT will count microseconds up to the ARR value.
// Basically ARR = n-1
// Set the ARPE bit in the CR1 so that the timer waits until the next
// update before changing the effective ARR value.
// Call NVIC_SetPriority() to set a low priority for Timer 2 interrupt.
// See the lab 6 text to understand how to do so.
void init_tim3(int n) {
    // TODO: you fill this in.
    RCC->APB1ENR |= (1<<1);//clock
    TIM3->PSC = 48-1;
    TIM3->ARR = n-1;
    TIM3->CR1 |= TIM_CR1_ARPE;

    NVIC_SetPriority(TIM3_IRQn,3);


    TIM3->DIER |= 1;
    TIM3->CR1 |= 1;
    NVIC->ISER[0] = 1<<16;
}


void TIM3_IRQHandler(void)
{
    // TODO: Remember to acknowledge the interrupt right here!
    TIM3->SR &= ~1;

    midi_play();
}

void startMusic(MIDI_Player * mp)
{
    init_wavetable_hybrid2();
    init_dac();
    init_tim15();
    mp = midi_init(midifile);
    // The default rate for a MIDI file is 2 beats per second
    // with 48 ticks per beat.  That's 500000/48 microseconds.
    init_tim3(10417);
//    for(;;) {
//        asm("wfi");
//        // If we hit the end of the MIDI file, start over.
//        if (mp->nexttick == MAXTICKS)
////            mp = midi_init(midifile);
//            break;
//    }
//    return mp;
}

void stopMusic(){
    TIM3->CR1 &= ~TIM_CR1_CEN;
    makeVoiceZero();
    //DAC->CR &= ~DAC_CR_EN1;
}
void startMusicAgain(MIDI_Player * id){
//    free(id);
    id = midi_init(midifile);
    return;
}
int checkMusicStatus(MIDI_Player * id){
    if (id->nexttick == MAXTICKS) return 1;

    return 0;
}
void unmuteMusic(MIDI_Player * id){
    //DAC->CR |= DAC_CR_EN1;

    id = midi_init(midifile);
    TIM3->CR1 |= TIM_CR1_CEN;
}

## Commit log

2022-05-16 Final Commit
    [New_configuration (1).cfg, New_configuration (2).cfg]
2022-05-16 Final Design and Code
    [ECE362 Mini Project.kicad_pcb, ECE362 Mini Project.kicad_sch]
